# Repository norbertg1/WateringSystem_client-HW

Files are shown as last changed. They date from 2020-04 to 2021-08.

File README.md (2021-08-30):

# Home watering system and weather station

The hardware is based on ESP8266. Its powered from LiFe battery which is chargerd from solar panel. The hardware wakes up every 10 minute (default), and login to mosquito message broker (on ubuntu) and publishes temperature, moisture, flow, etc.. If it is needed it can turn on the irrigation with H-bridge.
The connection between MySQL and Mosquitto is handled with short program written in Python.

**The PCB contains:** EPS8266, LiFe charger, battery voltage sensor, BMP280 sensor, soil moisture sensor, H-bridge for ball valve motor, flow meter.

#### **MySQL structure and settings:**

See: https://github.com/xnorbi/Watering-system/blob/master/server_on_ubuntu/MySQL/database_initialization_commands

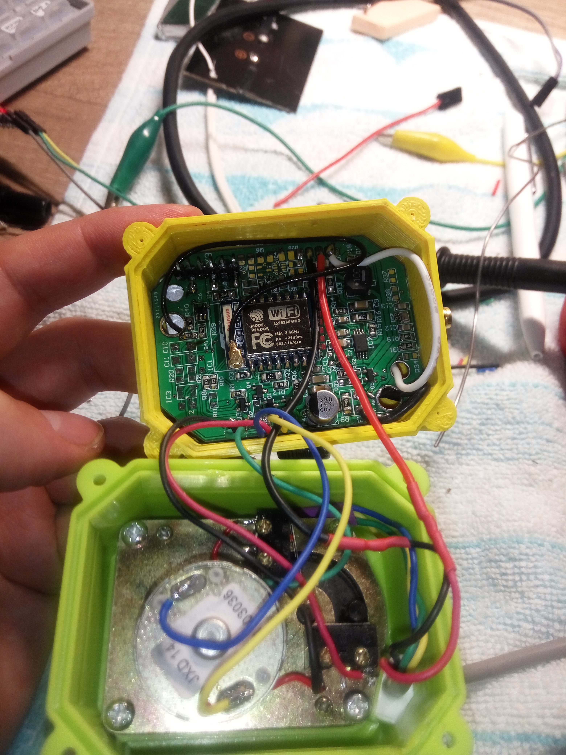
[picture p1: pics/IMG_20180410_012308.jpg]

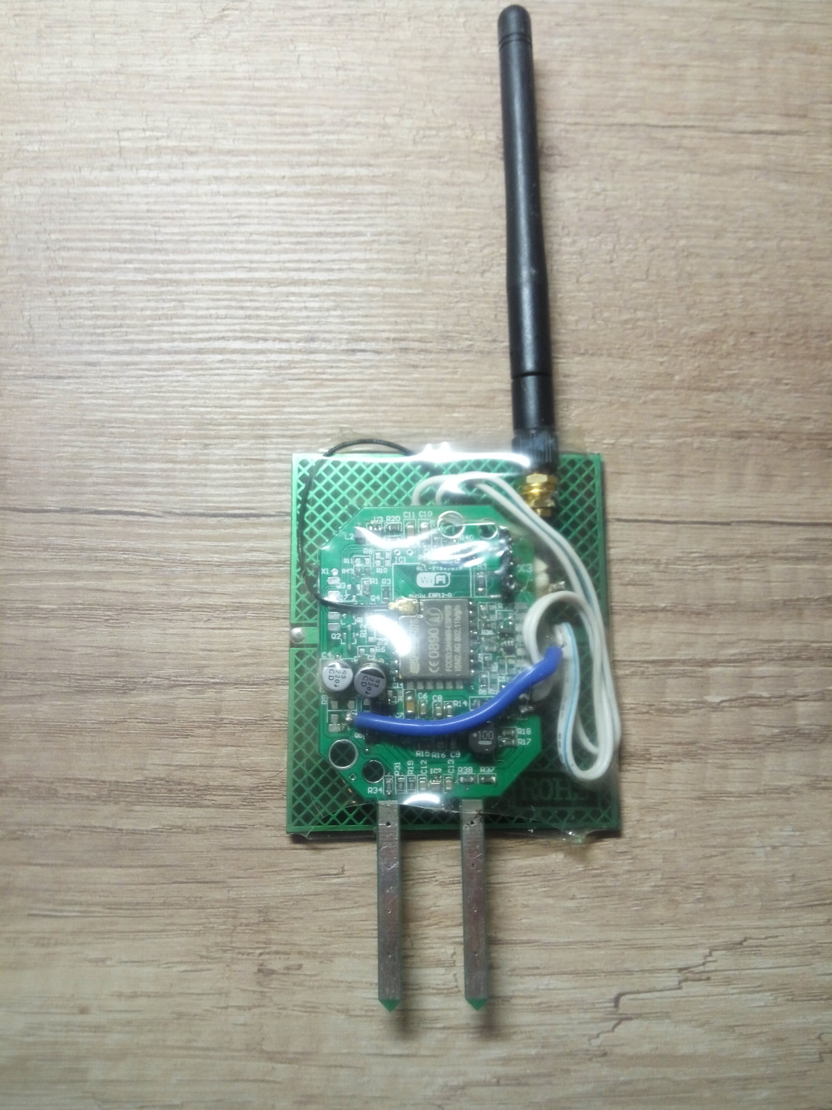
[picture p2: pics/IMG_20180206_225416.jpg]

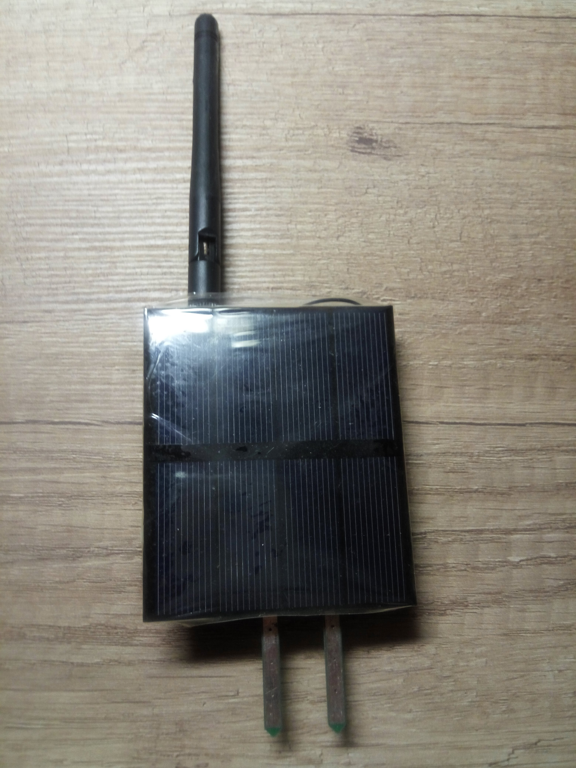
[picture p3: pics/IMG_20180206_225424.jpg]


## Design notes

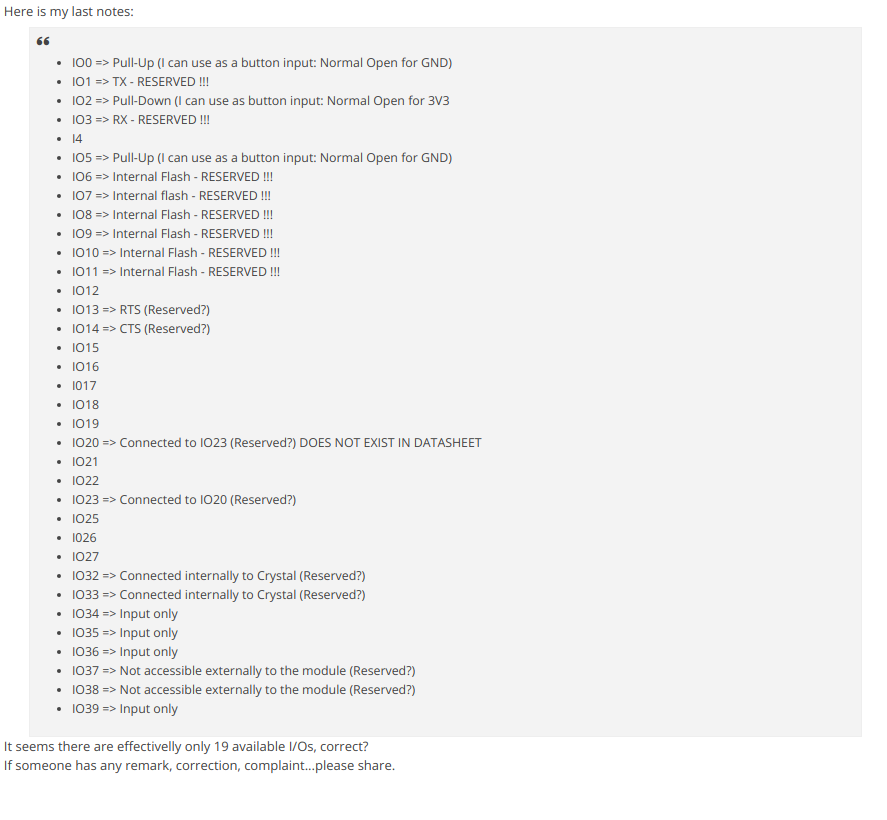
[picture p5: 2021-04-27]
Screenshot at 2021-04-03 15-27-58.png

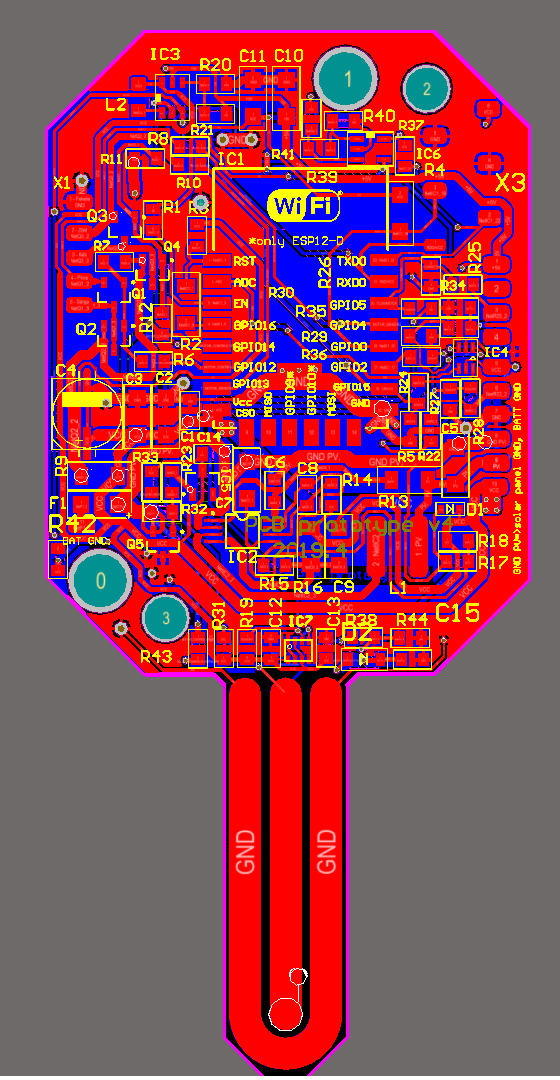
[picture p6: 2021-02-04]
pics/PCB.png

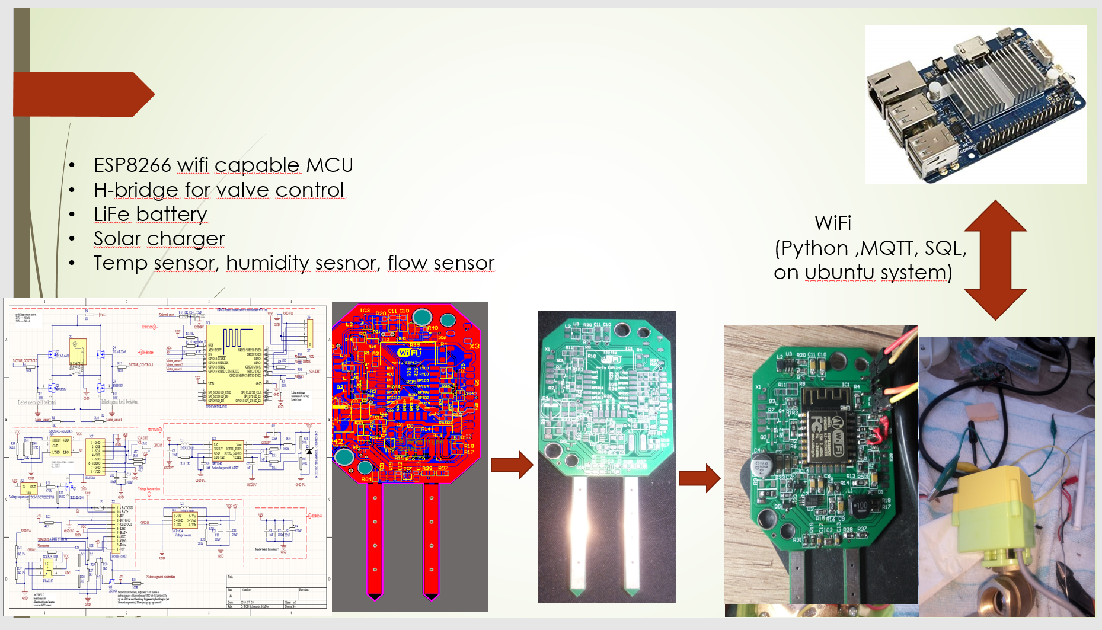
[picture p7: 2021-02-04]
pics/readme.png

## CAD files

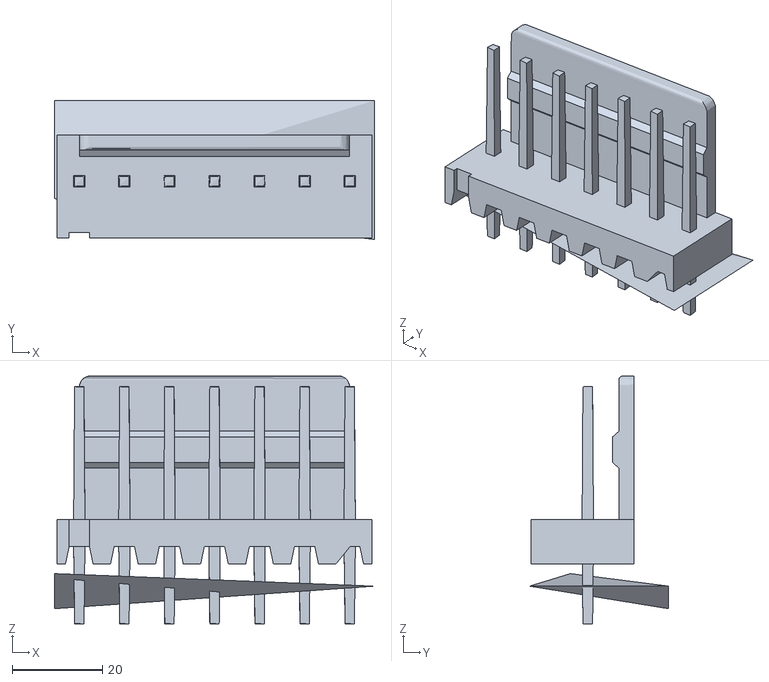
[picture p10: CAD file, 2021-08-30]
OBJ_NEW_PCB.obj
71.0 x 30.8 x 55.0

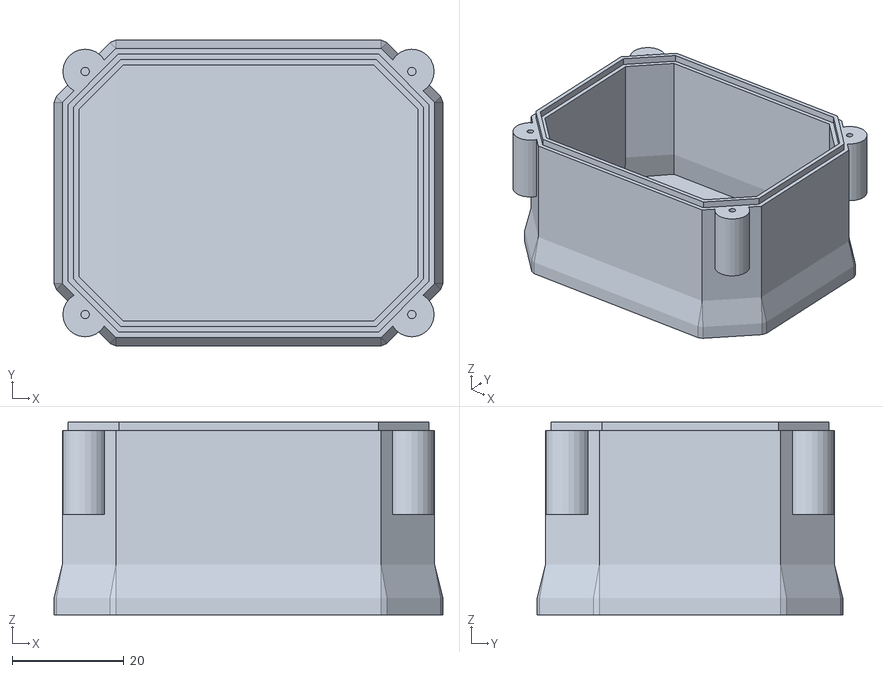
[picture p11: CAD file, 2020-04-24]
tető/teto motoros szelepre with solar panel.stl
69.7 x 54.8 x 34.5

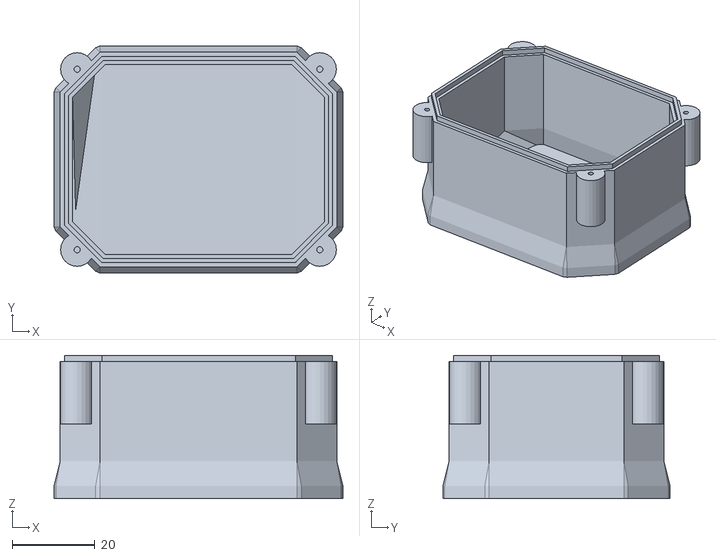
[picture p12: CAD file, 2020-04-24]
tető/gal.stl
69.7 x 54.8 x 34.5

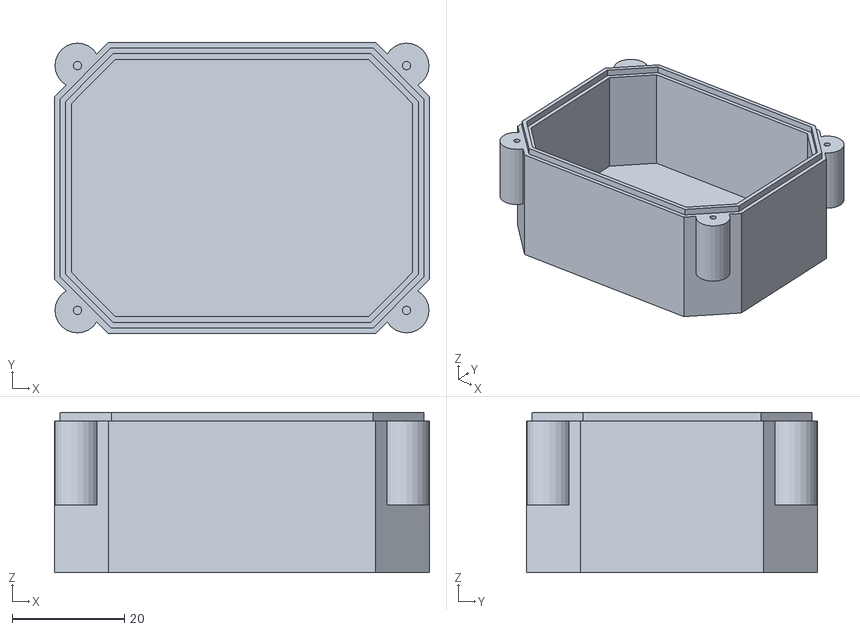
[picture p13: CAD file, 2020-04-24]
tető/teto motoros szelepre.stl
66.7 x 51.8 x 28.5

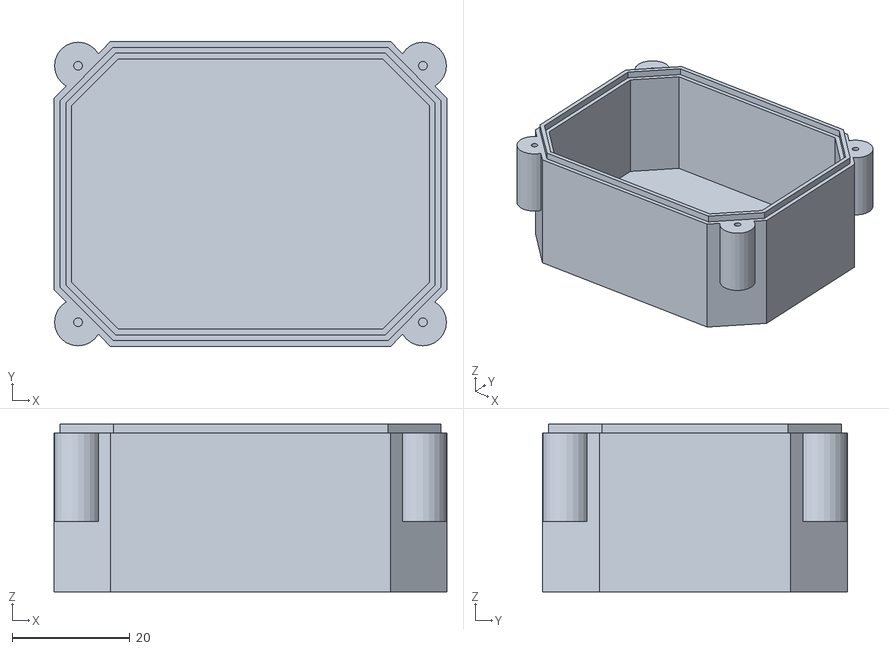
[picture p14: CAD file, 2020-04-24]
tető/teto motoros szelepre modified.stl
66.7 x 51.8 x 28.5

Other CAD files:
tető/gal repaired.stl
tető/teto motoros szelepre with solar panel(1).stl
tető/teto motoros szelepre modified.skp
tető/teto motoros szelepre.skp

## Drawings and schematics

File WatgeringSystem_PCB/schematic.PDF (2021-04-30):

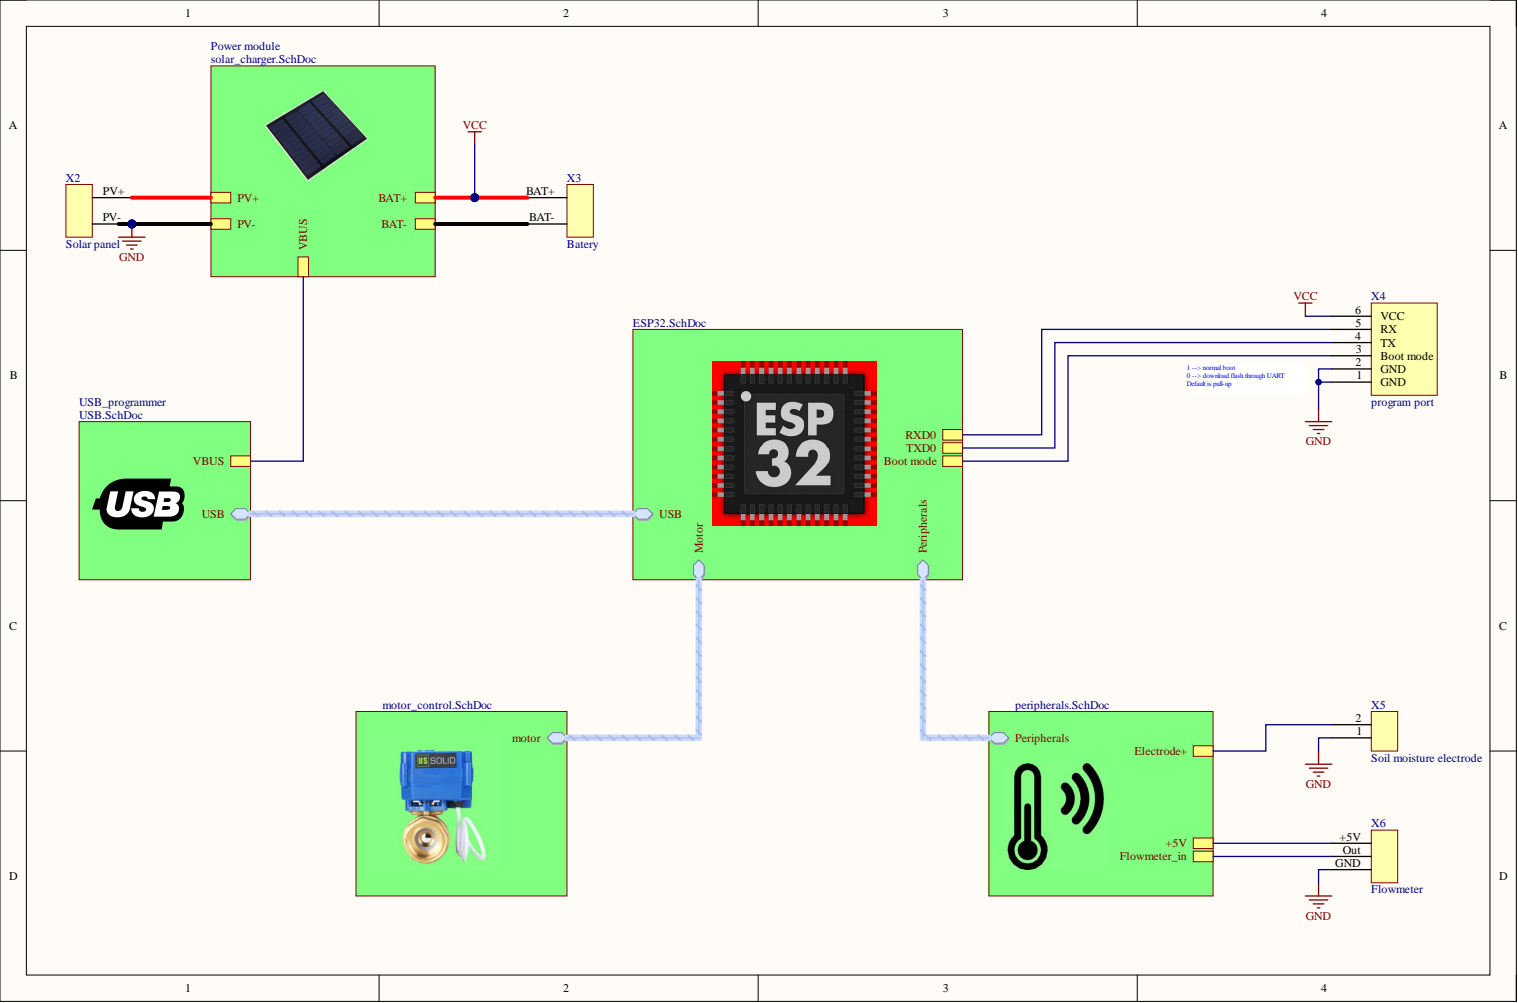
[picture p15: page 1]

USB | | 4

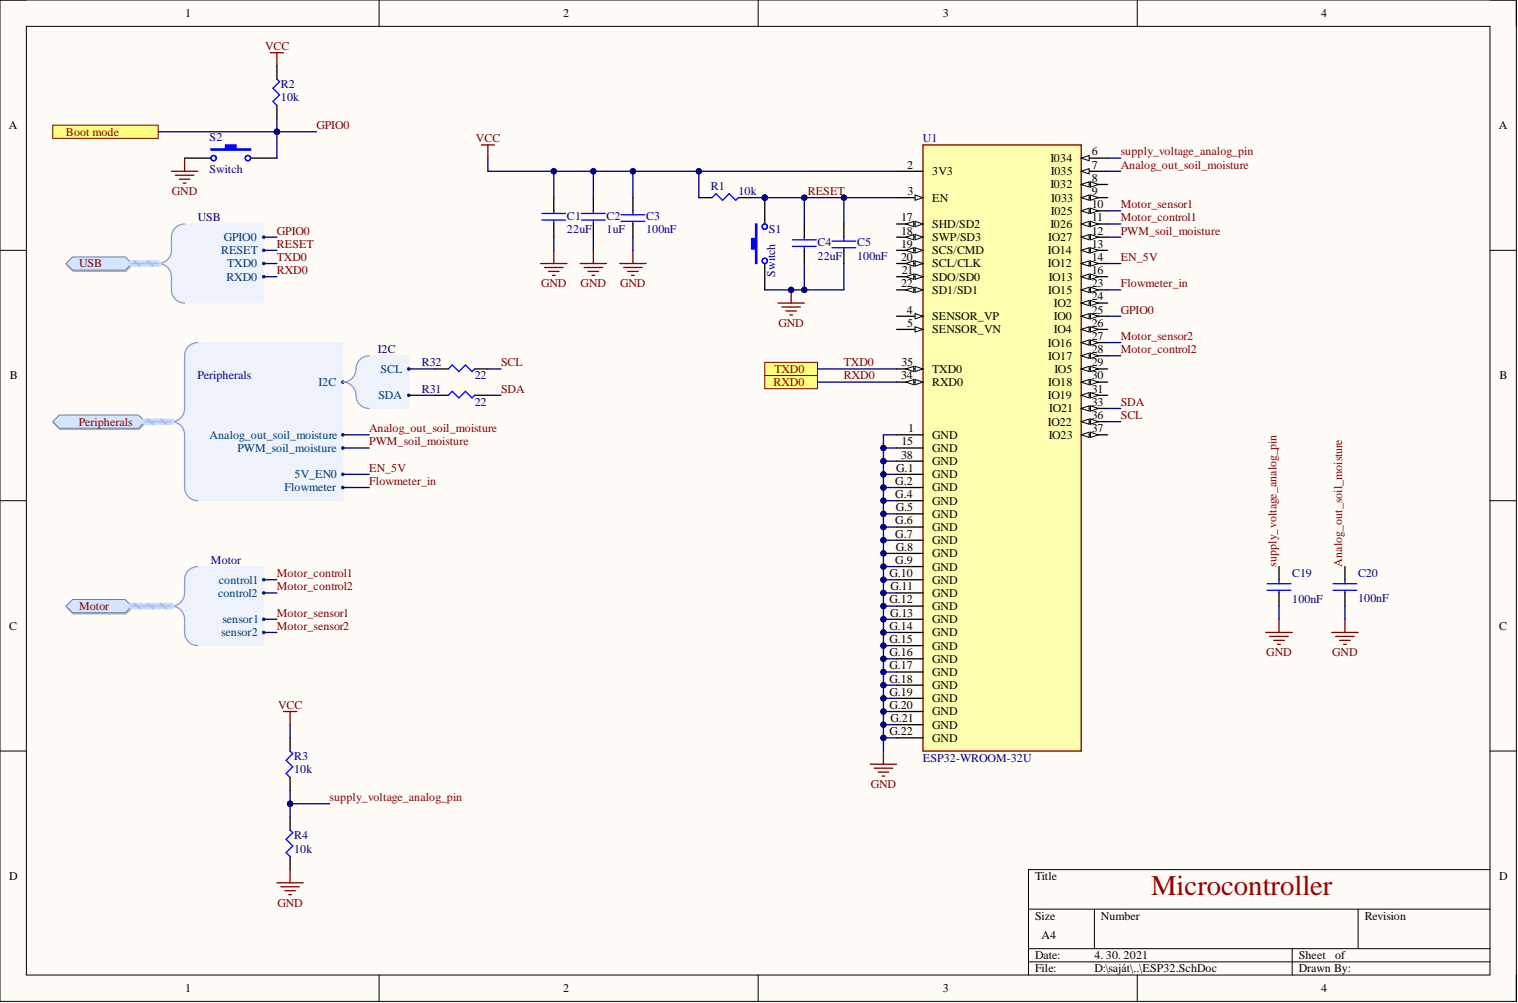
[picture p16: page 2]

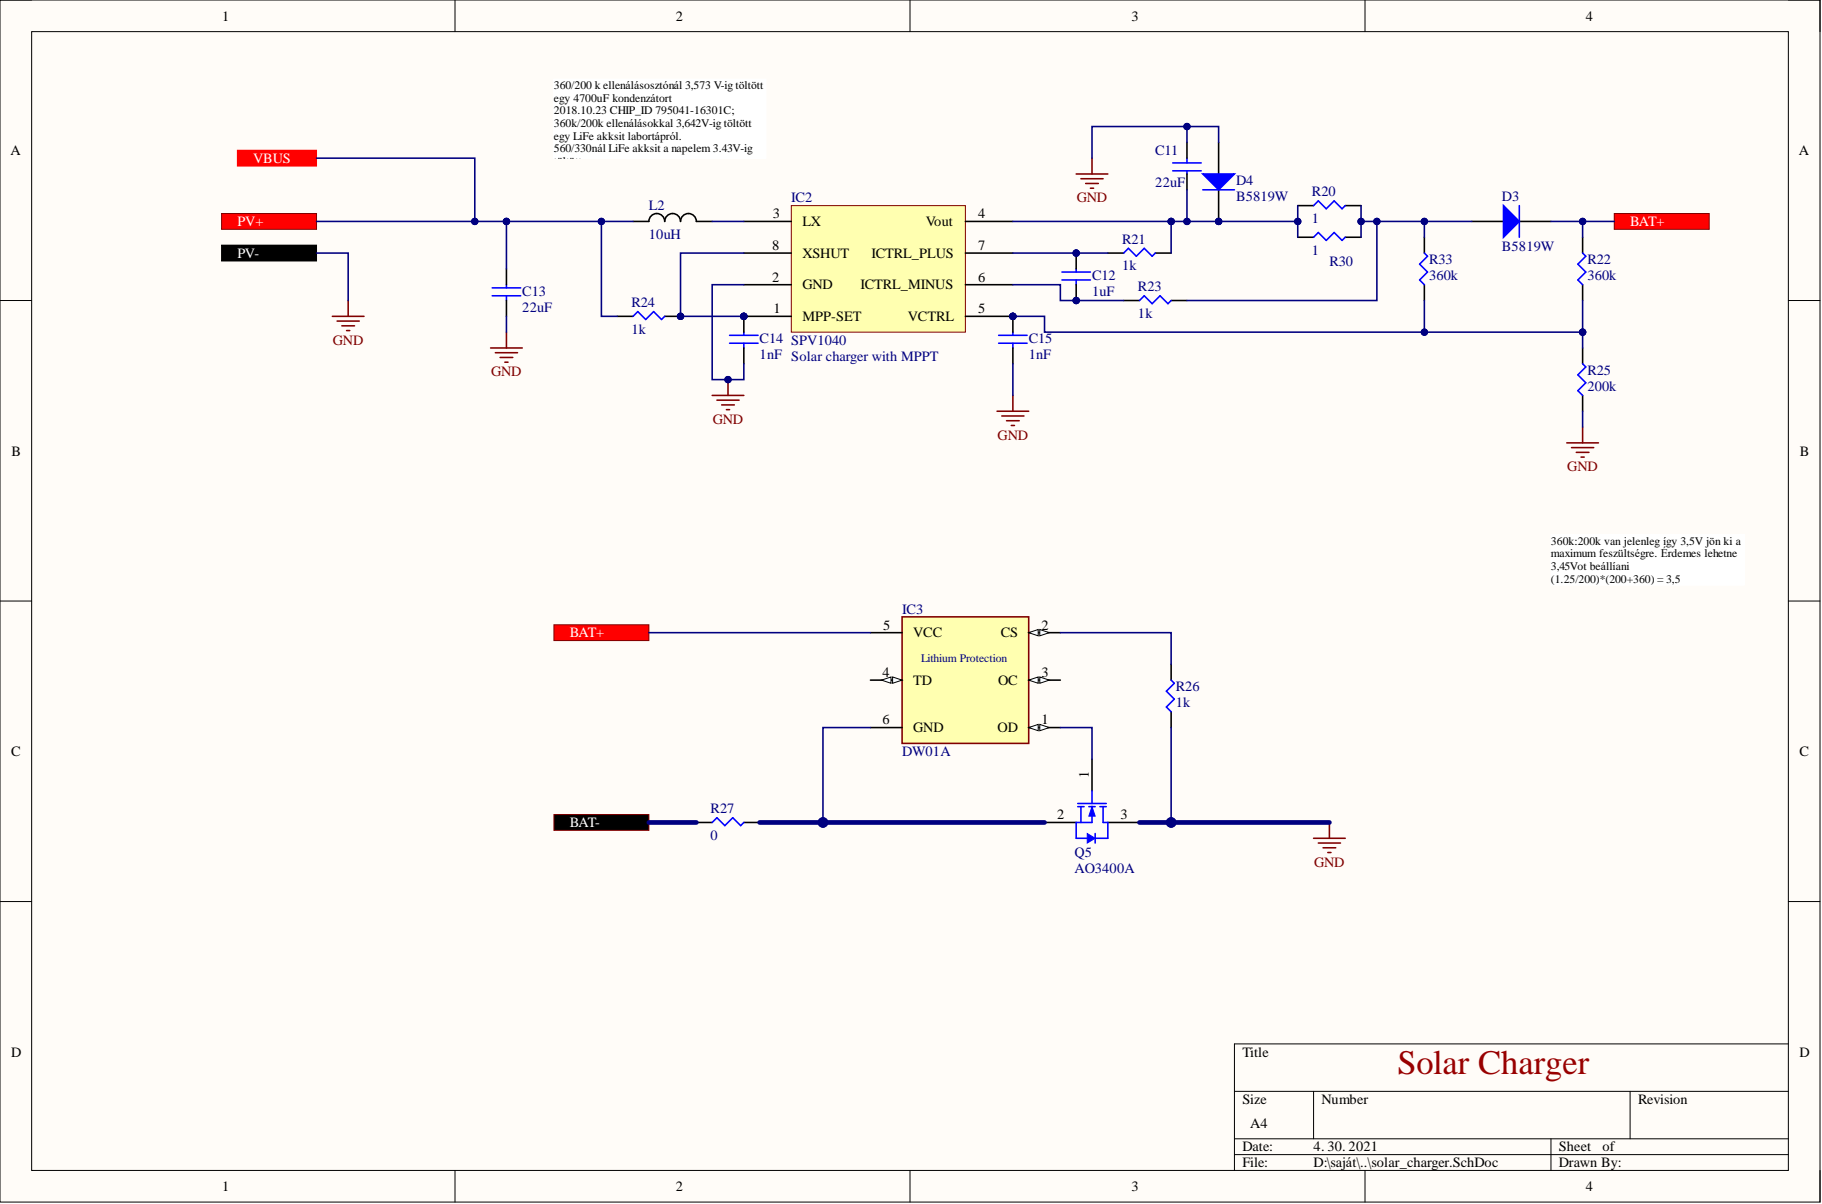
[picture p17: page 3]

360/200 k ellenálásosztónál 3,573 V-ig töltött
egy 4700uF kondenzátort
2018.10.23 CHIP_ID 795041-16301C;
360k/200k ellenálásokkal 3,642V-ig töltött
egy LiFe akksit labortápról.
560/330nál LiFe akksit a napelem 3.43V-ig
töltött

360k:200k van jelenleg így 3,5V jön ki a
maximum feszültségre. Érdemes lehetne
3,45Vot beállíani

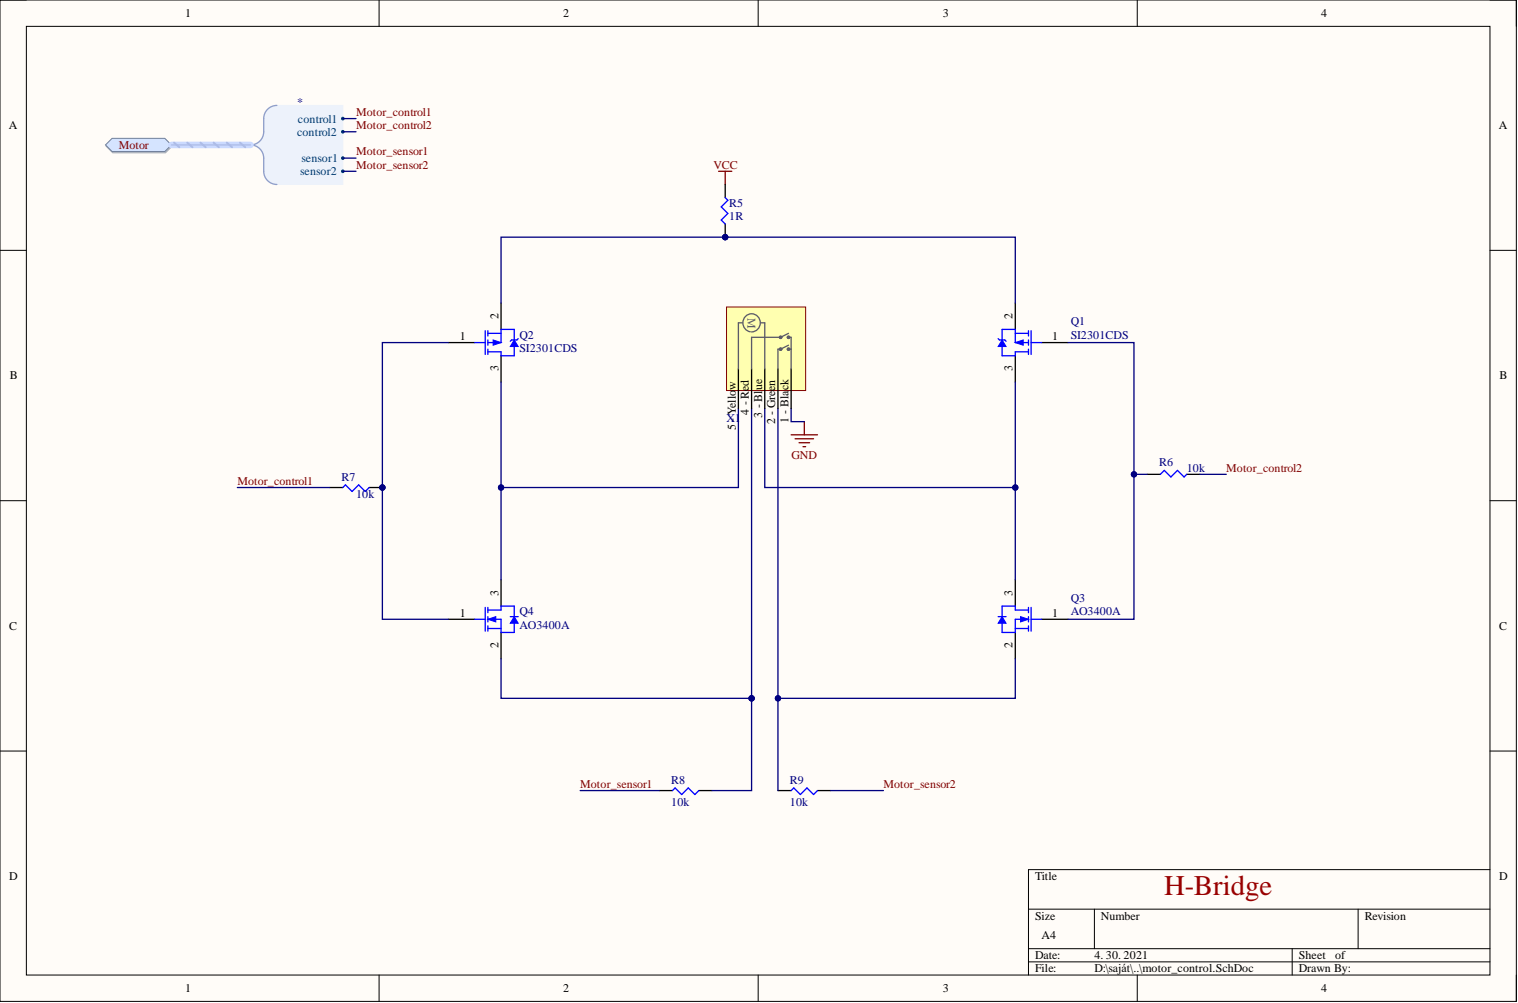
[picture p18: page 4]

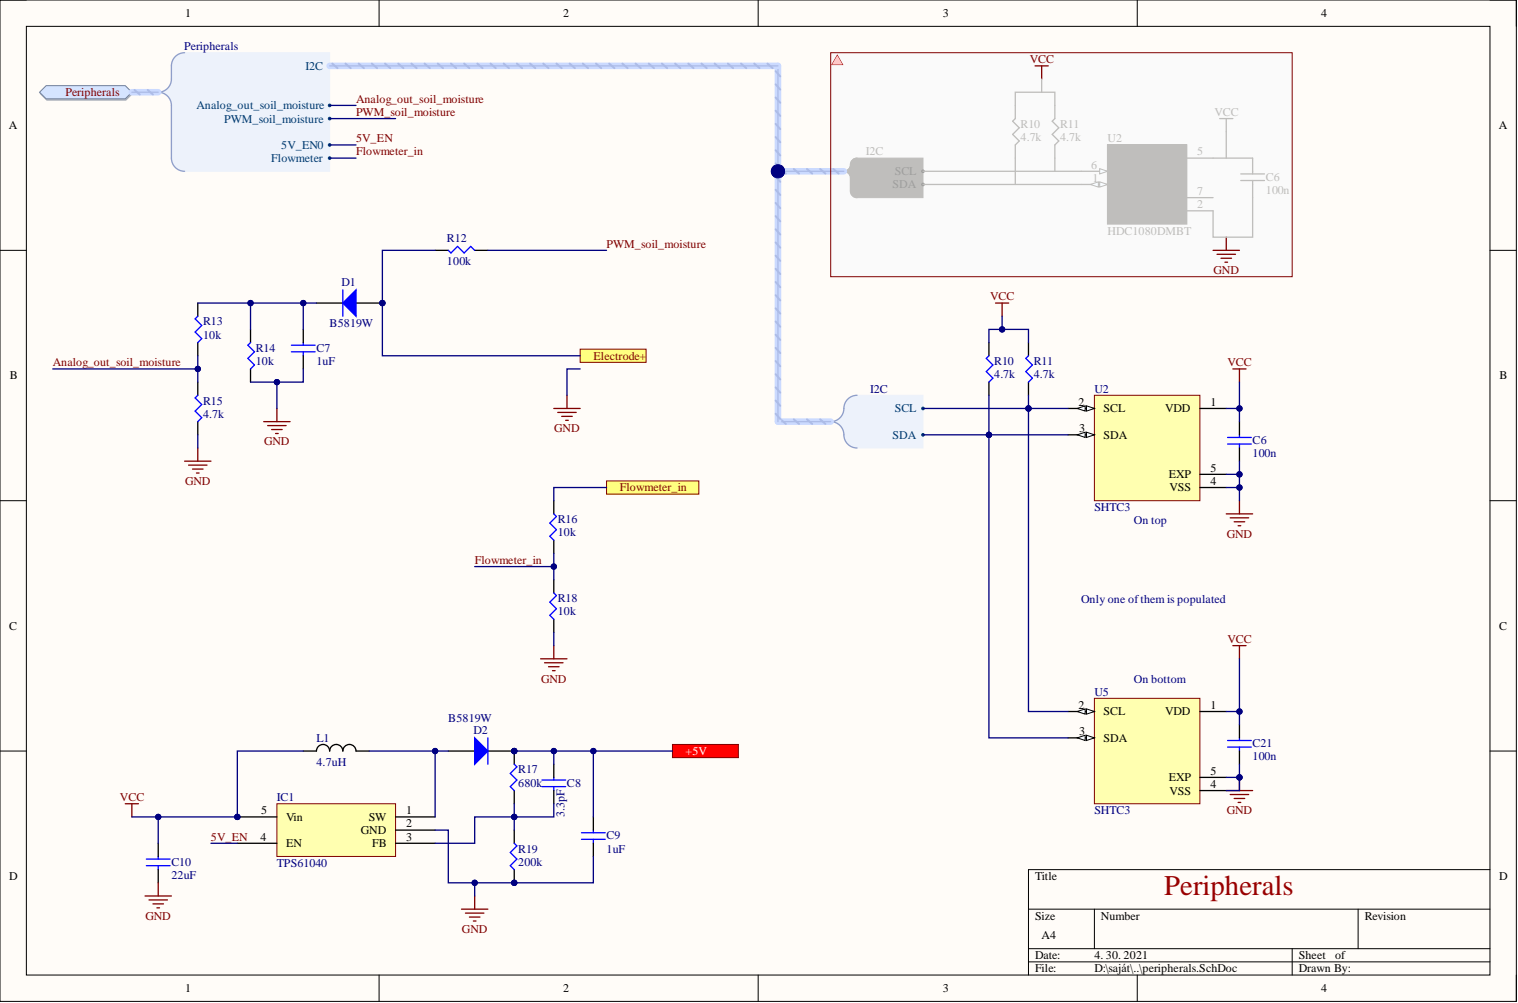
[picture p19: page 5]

Only one of them is populated

Vin 5 | GND
EN 4 | 2

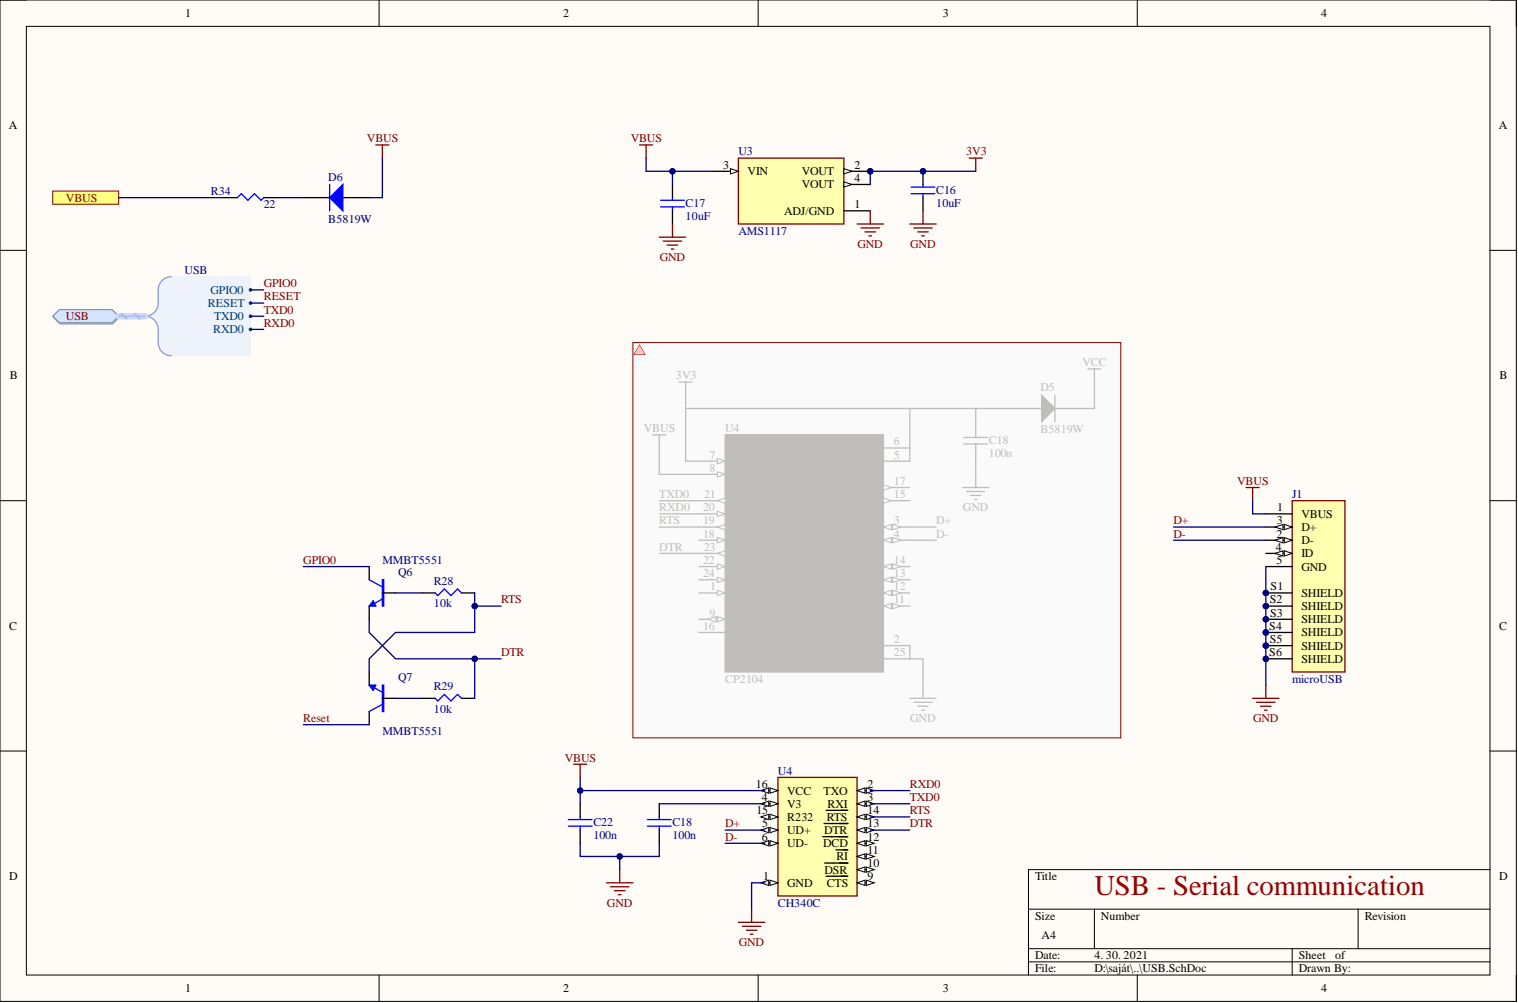
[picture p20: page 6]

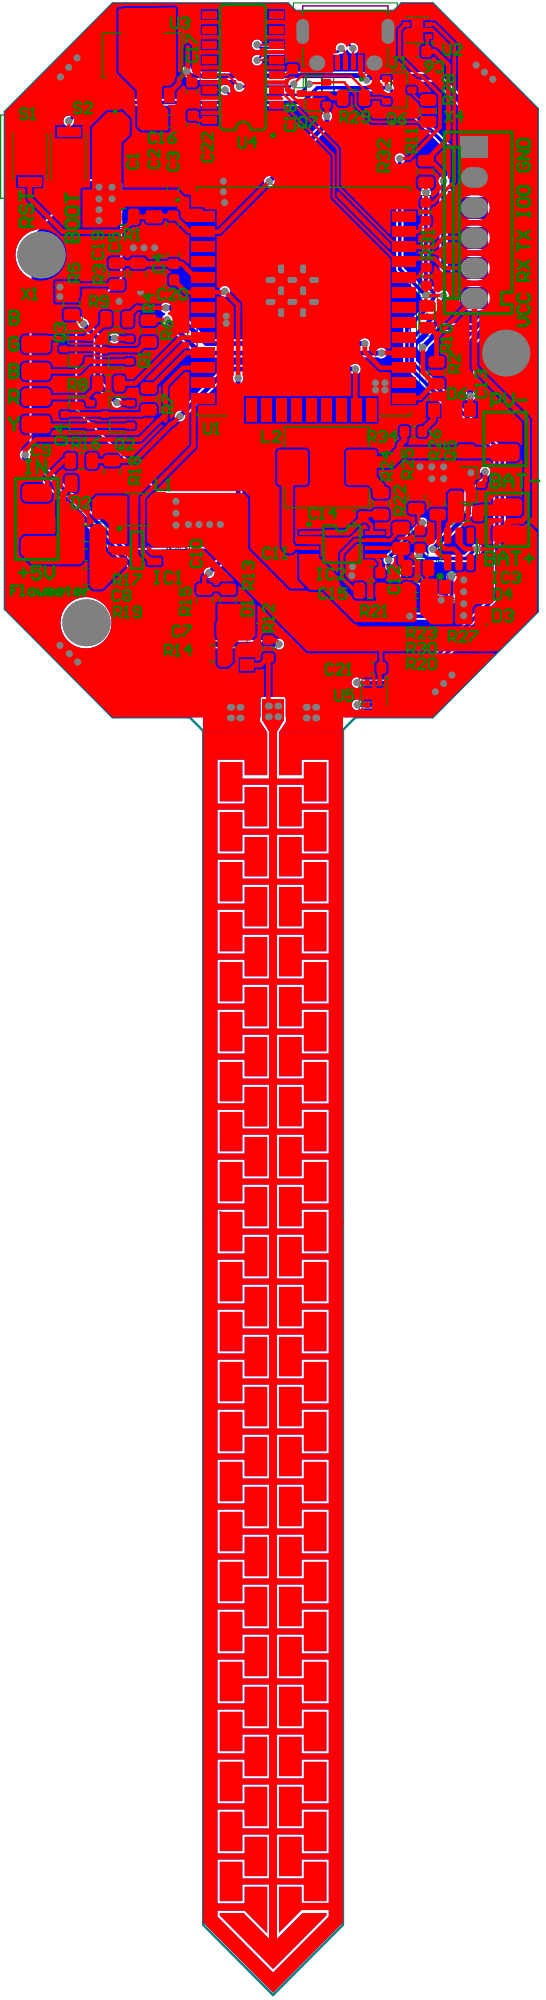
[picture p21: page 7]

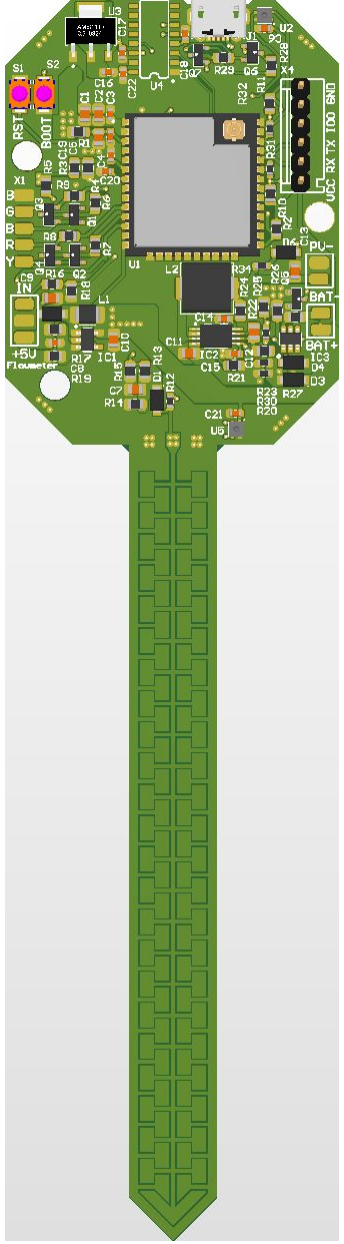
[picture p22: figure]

Designator | Quantity | Comment | LCSC Part # | Description | Footprint | LibRef
R1, R2, R3, R4, R6, R7, R8, R9, R13, R14, R16, R18, R28, R29 | 14 10k | | C17414 | | RESC200X125X70L40N | Resistor
C1, C4, C10, C11, C13 | 5 22uF | | C59461 | | CAPC200X125X110L50 N | Capacitor
D1, D2, D3, D4, D6 | 5 B5819W | | C8598 | | SODFL350X110-2N | Diode
C2, C7, C9, C12 | 4 1uF | | C15849 | | CAPC200X125X110L50 N | Capacitor
C3, C5, C19, C20 | 4 100nF | | C14663 | | CAPC160X80X90L35N | Capacitor
C6, C18, C21, C22 | 4 100n | | [NoValue], C14663 | | CAPC160X80X90L35N | Capacitor
R21, R23, R24, R26 | 4 1k | | C17513 | | RESC200X125X70L40N | Resistor
Q3, Q4, Q5 | 3 AO3400A | | C20917 | N-FET | SOT23-3P95_240X114L20X40 N | N-FET
R10, R11, R15 | 3 4.7k | | C17673 | | RESC200X125X70L40N | Resistor
R31, R32, R34 | 3 22 | | C23345 | | RESC160X80X90L30N | Resistor
C14, C15 | 2 1nF | | C1588 | | CAPC160X80X90L35N | Capacitor
C16, C17 | 2 10uF | | C19702 | | CAPC160X80X90L35N | Capacitor
Q1, Q2 | 2 SI2301CDS | | C10487 | P-FET | SOT23-3P95_240X114L20X40 N | P-FET
Q6, Q7 | 2 MMBT5551 | | C2145 | Bipolar _BJT_ Transistor NPN 160V 600mA 225mW Surface Mount SOT-23-3 _TO-236_ | SOT23-3P95_240X114L20X40 N | MMBT5551
R19, R25 | 2 200k | | C17539 | | RESC200X125X70L40N | Resistor
R20, R30 | 2 1 | | C22936 | | RESC160X80X90L30N | Resistor
R22, R33 | 2 360k | | C23146, not polluted | | RESC160X80X90L30N | Resistor
S1, S2 | 2 Switch | | C115357 | Switch | SKRKAEE020 | Switch
U2, U5 | 2 SHTC3 | | [NoValue], C194656 | | SHTCx | SHTCx
C8 | 1 3.3pF | | C46219 | Optional | CAPC160X80X90L35N | Capacitor
IC1 | 1 TPS61040 | | C7722 | | SOT23-5 | TPS61040
IC2 | 1 SPV1040 | | C221500 | | SPV1040 | SPV1040
IC3 | 1 DW01A | | C61503 | Pushbutton Switch SPST-NC Standard Panel Mount, Front | CFP6P95_290X280X14 5L45X40N | DW01A
J1 | 1 microUSB | | C404969 | Micro USB | SHOUHAN_MICROXN J | microUSB
L1 | 1 4.7uH | | C1049 | INDUCTOR | INDM320X250X240L5 5X190N | INDUCTOR
L2 | 1 10uH | | C132141 | INDUCTOR | INDM730X660X300L1 60X290N | INDUCTOR
R5 | 1 1R | | C25271 | | RESC200X125X70L40N | Resistor
R12 | 1 100k | | C17407 | | RESC160X80X90L30N | Resistor
R17 | 1 680k | | C17797 | | RESC200X125X70L40N | Resistor
R27 | 1 0 | | C17477 | This is a fuse!!! | RESC200X125X70L40N | Resistor
U1 | 1 ESP32-WROOM-32U | | C277944 | Bluetooth, WiFi 802.11b/g/n, Bluetooth v4.2 +EDR, Class 1, 2 and 3 Transceiver Module 2.4GHz ~ 2.5GHz Antenna Not Included, U.FL Surface Mount | ESP32-WROOM-32U | ESP32-WROOM-32U
U3 | 1 AMS1117 | | C6186 | UNO PLUS Arduino R3 Shield, Xbee Arduino IDE Wheeled Robotics Kit | SOT229P700X180-4N | AMS1117
U4 | 1 CH340C | | C84681 | USB to serial chip CH340 | SO016 | CH340C
X1 | 1 motor_connector | | | | motor_connector | motor_connector
X2 | 1 Solar panel | | | | Solar Panel connenctor | Solar panel
X3 | 1 Batery | | | | Battery connector | Batery
X4 | 1 program port | | C239366 | | A2543WV-6P | program port - 6 pin
X5 | 1 Soil moisture | electrode | | | Soil moisture sensor -long | Soil moisture sensor
X6 | 1 Flowmeter | | | | Flowmeter | Flowmeter

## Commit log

2020-04-24 Initial commit. Branched from big project where software and hardware where together.
    [Locsolo.PrjPcb, PCB-sensor.PcbDoc, PCB.PcbDoc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]
2020-07-29 Major cosmetical changes. Proper BOM list in progress.
    [H-bridge.SchDoc, Locsolo.PrjPcb, PCB.PcbDoc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]
2021-02-04 New pictures added.
    [Locsolo.PrjPcb, PCB.PcbDoc, Schematic.SchDoc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]
2021-03-17 strated hardware design of v2.0
    [Locsolo.PrjPcb, PCB.PcbDoc, Schematic.SchDoc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]
2021-03-30 Started working on v2.0.
    [ESP32.SchDoc, H-bridge.SchDoc, Locsolo.PrjPcb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]
2021-03-30 v2.0 design completed, some supervision needed before the manufacturing.
    [ESP32.SchDoc, PCB.PcbDoc, USB.SchDoc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]
2021-03-31 HDC1080 sensor changed to SHT3, diode between solar panel and charger moved betwwen the charger and battery.
    [ESP32.SchDoc, PCB.PcbDoc, WateringSystem_lib.PcbLib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]
2021-04-02 Soil moisture electrode lenght extended. Added one more place for SHT3 sensor.
    [ESP32.SchDoc, PCB.PcbDoc, USB.SchDoc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]
2021-04-02 Added possibility to charge from USB connection.
    [PCB.PcbDoc, USB.SchDoc, main.SchDoc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]
2021-04-27 CP2104 changed to CH340. Tactile switch type changed. Added tactile switch for boot mode.
    [ESP32.SchDoc, PCB.PcbDoc, USB.SchDoc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]
2021-04-30 Output job for PDF generation added, schematic.pdf generated. Some cosmetical changes on shcematic.
    [ESP32.SchDoc, PCB.PcbDoc, USB.SchDoc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]
2021-08-30 Changes over USB controller.
    [ESP32.SchDoc, OBJ_NEW_PCB.obj, PCB.PcbDoc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]
